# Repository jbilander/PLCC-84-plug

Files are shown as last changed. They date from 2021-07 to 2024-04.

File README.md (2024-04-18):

# PLCC-84-plug
A PLCC-84 plug adapter created out of PCBs

***
Please note, The first revision Rev1A of this plug isn't optimal for SMD-sockets, it is a little too small to give a solid connection on all pins. It fits well and gives good connection in the seemingly tighter PLCC-84-TH-sockets though. A new revision 1C is in the works aiming for that 30.1-30.2 mm sweetspot.

_UPDATE: The Rev.1C is finished and gerbers available for download under Releases as well:_

***

REV 1C:<br /><br />
<a href="images/PLCC_84_Plug_pcbs_rev1c.jpg">
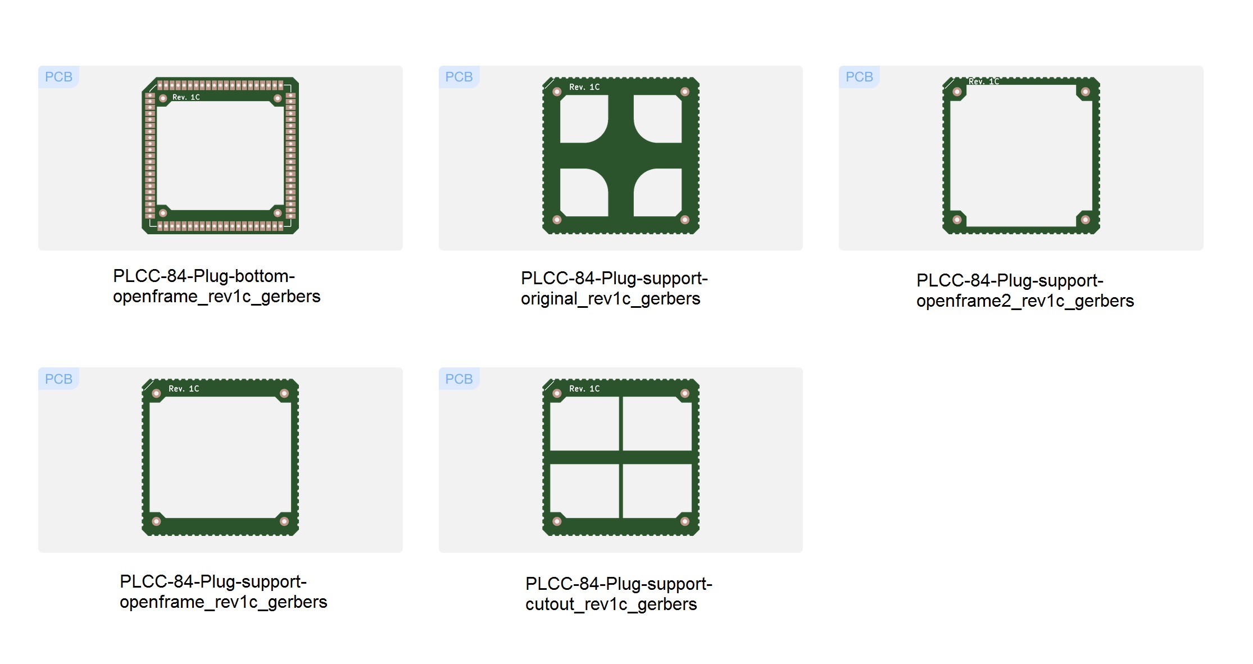
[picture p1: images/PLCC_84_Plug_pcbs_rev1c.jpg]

</a>

***

REV 1B:

<br />
<a href="images/PLCC_84_Plug_build_pic13.jpg">
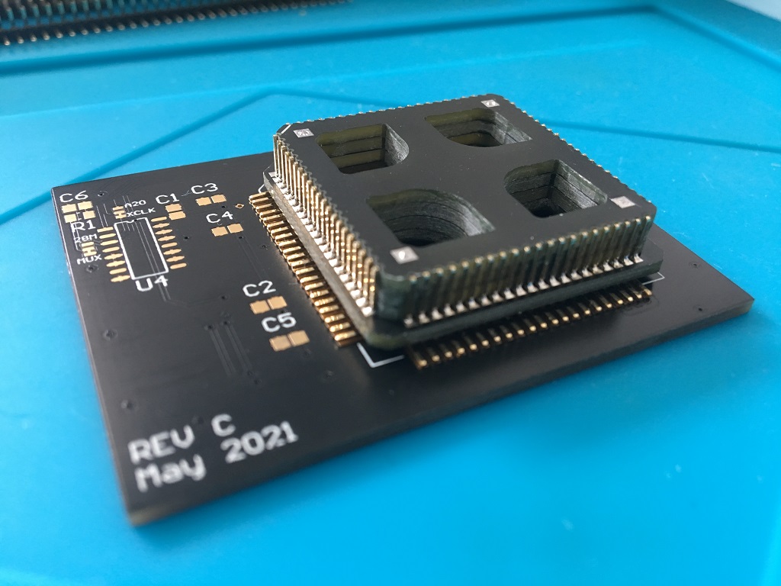
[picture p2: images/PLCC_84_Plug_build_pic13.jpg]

</a>
<br />

Suitable pin headers to use with this plug:<br />
1.27 mm 50 P 1 x 50 Pin Header Single row Right Angle Male<br />
https://www.aliexpress.com/item/32767692043.html
<br /><br />
If you use the pins from the link (0.4mm square) you will get to ~30.2 mm, with the MPE 332-1-040 pins you will end up at ~30.4mm which is perhaps a bit too much for a TH-socket.
<br /><br />
<a href="images/PLCC_84_Plug_build_pic16.jpg">
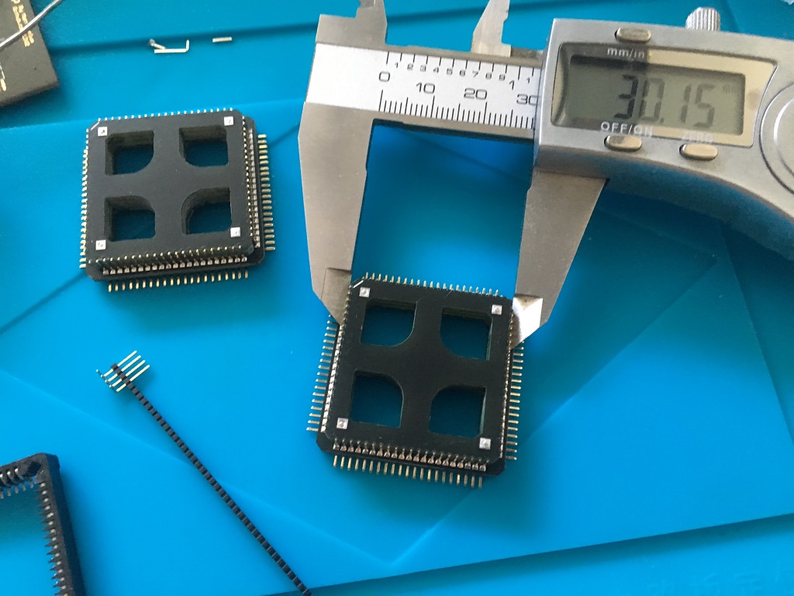
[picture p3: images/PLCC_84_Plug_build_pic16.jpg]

</a>
<a href="images/PLCC_84_Plug_build_pic15.jpg">
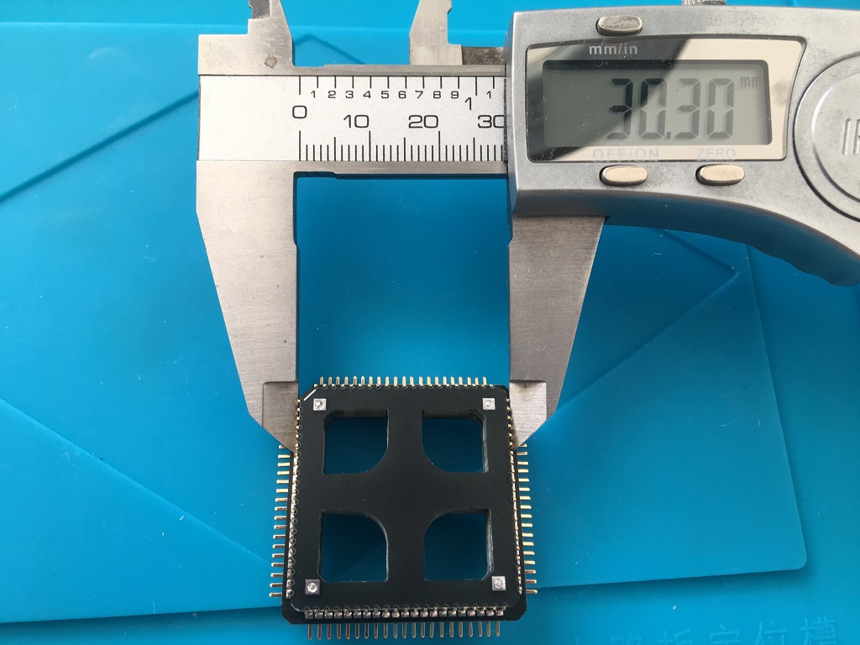
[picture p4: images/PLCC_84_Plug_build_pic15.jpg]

</a>
<a href="images/PLCC_84_Plug_build_pic14.jpg">
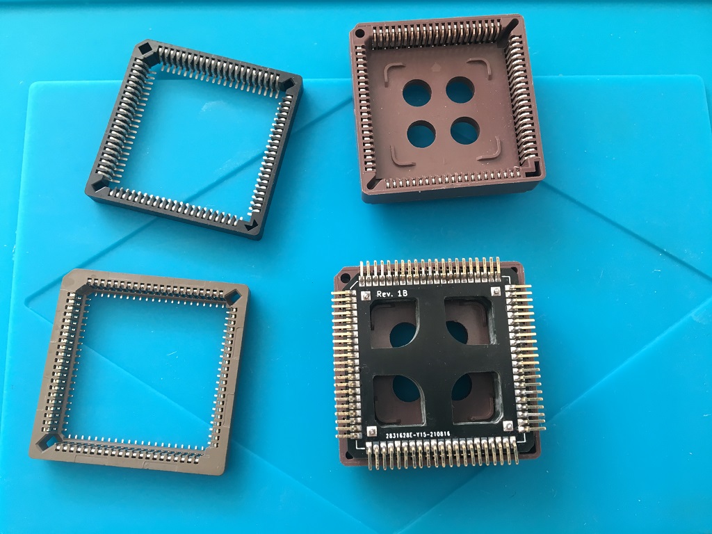
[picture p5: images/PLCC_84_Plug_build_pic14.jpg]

</a>

***

With this kind of footprint on the PCB it will take both variants of the plug. Both one with the angled SMT headers like above and one with straight TH-pins like on pics below. As you can see there's no need for the base PCB in the latter case since that footprint is now directly on the main PCB.

***

<a href="images/PLCC_84_Plug_build_pic18.jpg">
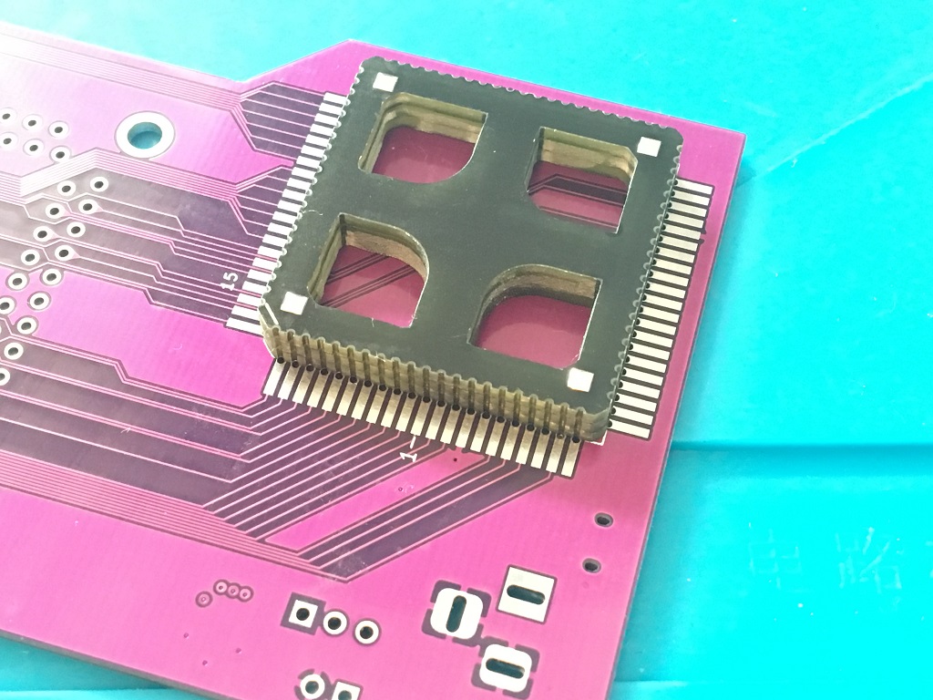
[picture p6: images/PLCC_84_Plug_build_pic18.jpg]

</a>
<a href="images/PLCC_84_Plug_build_pic19.jpg">
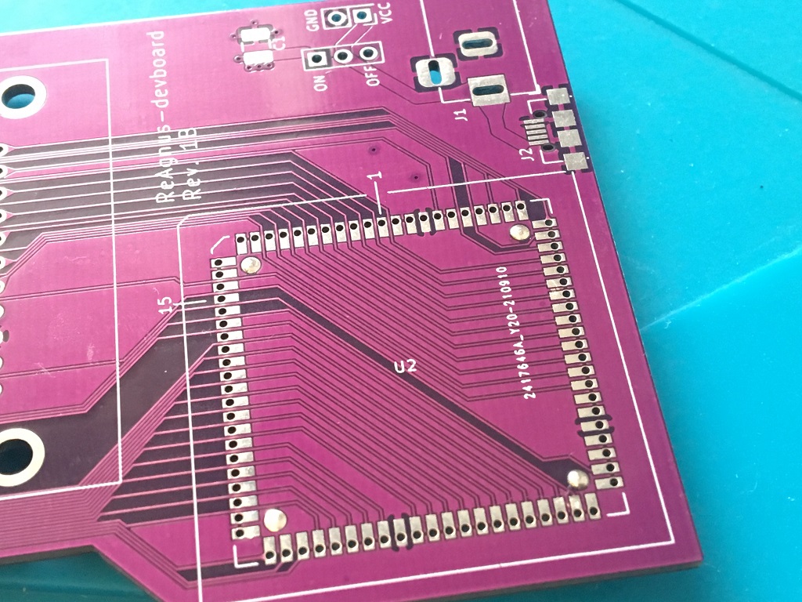
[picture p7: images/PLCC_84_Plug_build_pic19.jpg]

</a>
<a href="images/PLCC_84_Plug_build_pic20.jpg">
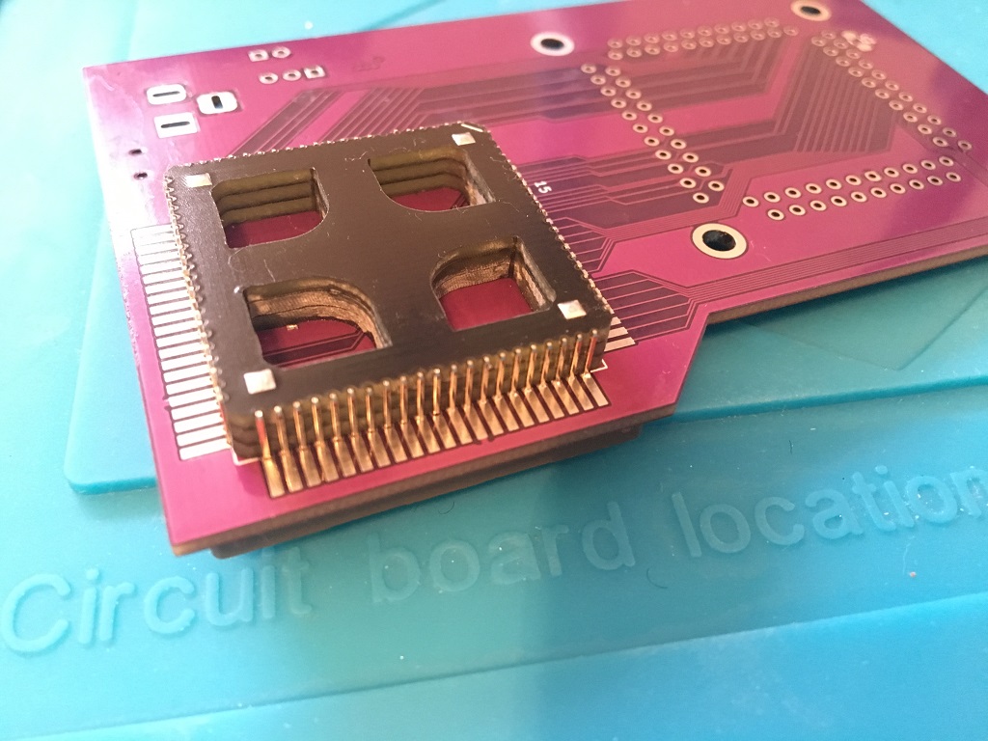
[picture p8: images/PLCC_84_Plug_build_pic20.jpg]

</a>

***

REV 1A:

<br />
<a href="images/PLCC_84_HomebrewPlug_rev1a_vs_Winslow_plug.jpg">
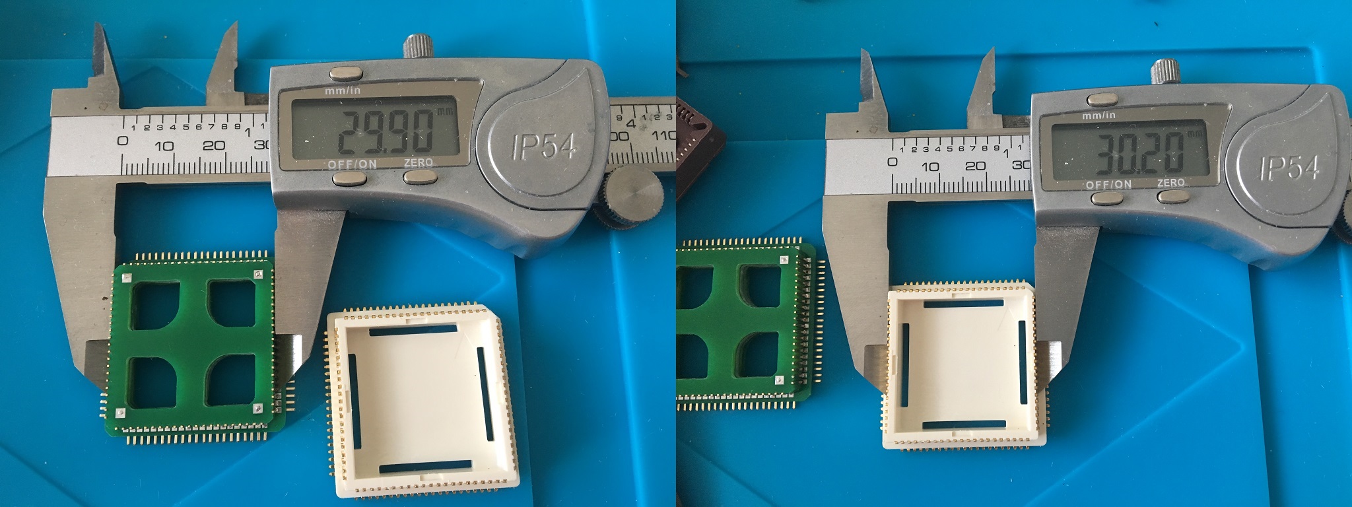
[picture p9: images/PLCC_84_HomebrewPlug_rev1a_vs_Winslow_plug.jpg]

</a>
<br />

Suitable pin headers to use building this plug:<br />
_MPE 332-1-040 Pin headers 2.00 mm, 1X40, angled_ <br />
https://www.reichelt.com/se/en/pin-headers-2-00-mm-1x40-angled-mpe-332-1-040-p119983.html

***

Building: <br />

First use a TH-socket as a Jig and put three support PCBs in the socket, pay attention to orientation (the silk screen marking in the corner). Now put two straight header pins (taken from a 2.0mm pin pitch header) in each corner to center align the PCBs. Now put the bottom PCB in place and put fatter pins (from a 2.54mm pin pitch header) in each of the TH-pad corners and solder to lock everything in position. Cut the four pins with a wire cutter<br />

***

<a href="images/PLCC_84_Plug_build_pic1.jpg">
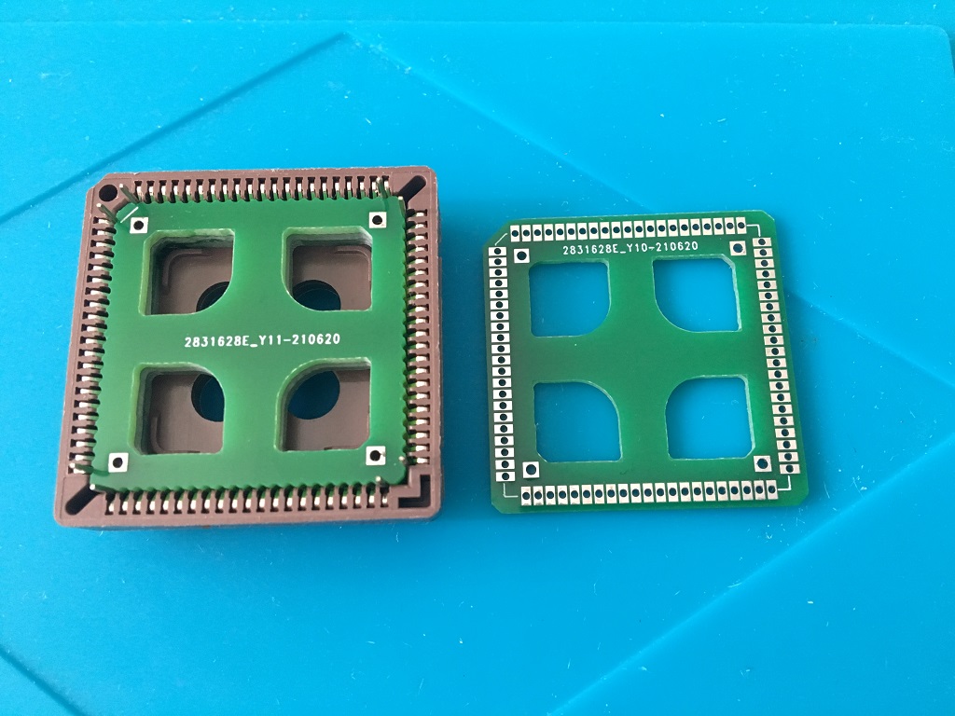
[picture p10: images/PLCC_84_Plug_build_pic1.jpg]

</a>
<a href="images/PLCC_84_Plug_build_pic2.jpg">
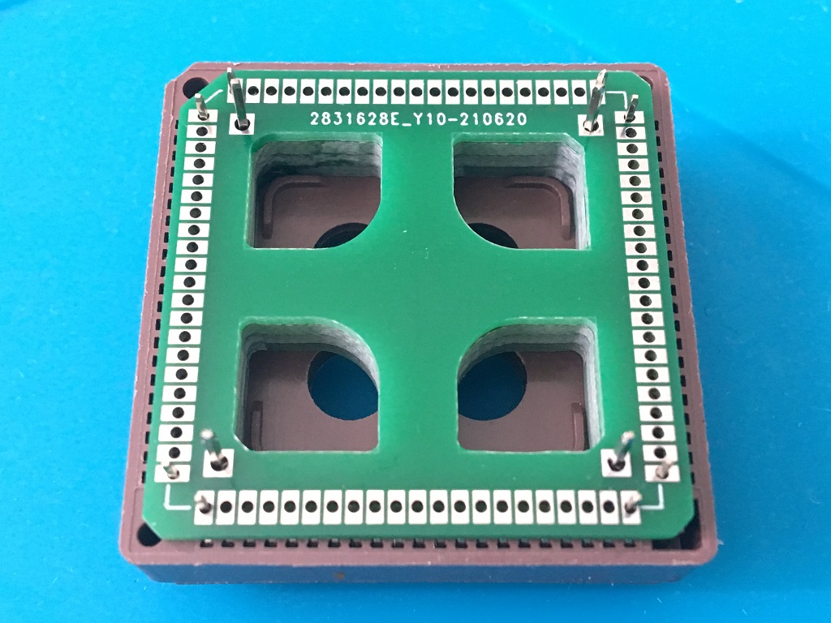
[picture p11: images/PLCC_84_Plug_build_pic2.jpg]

</a>
<br />
<a href="images/PLCC_84_Plug_build_pic3.jpg">
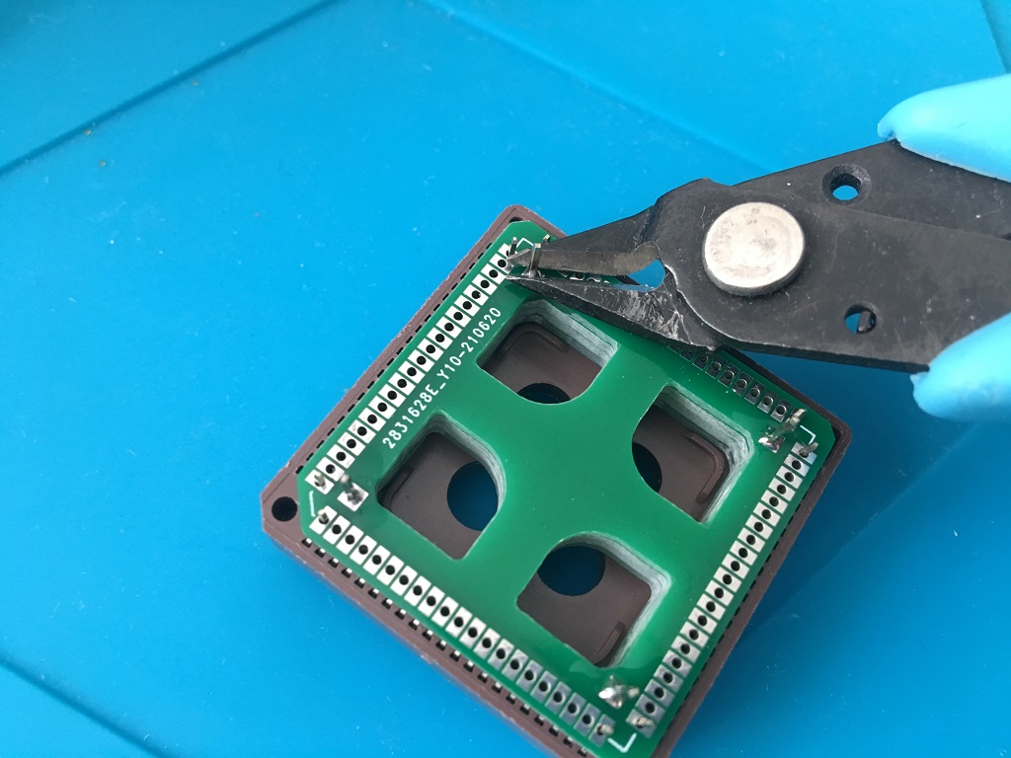
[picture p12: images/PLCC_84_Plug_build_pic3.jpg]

</a>
<a href="images/PLCC_84_Plug_build_pic4.jpg">
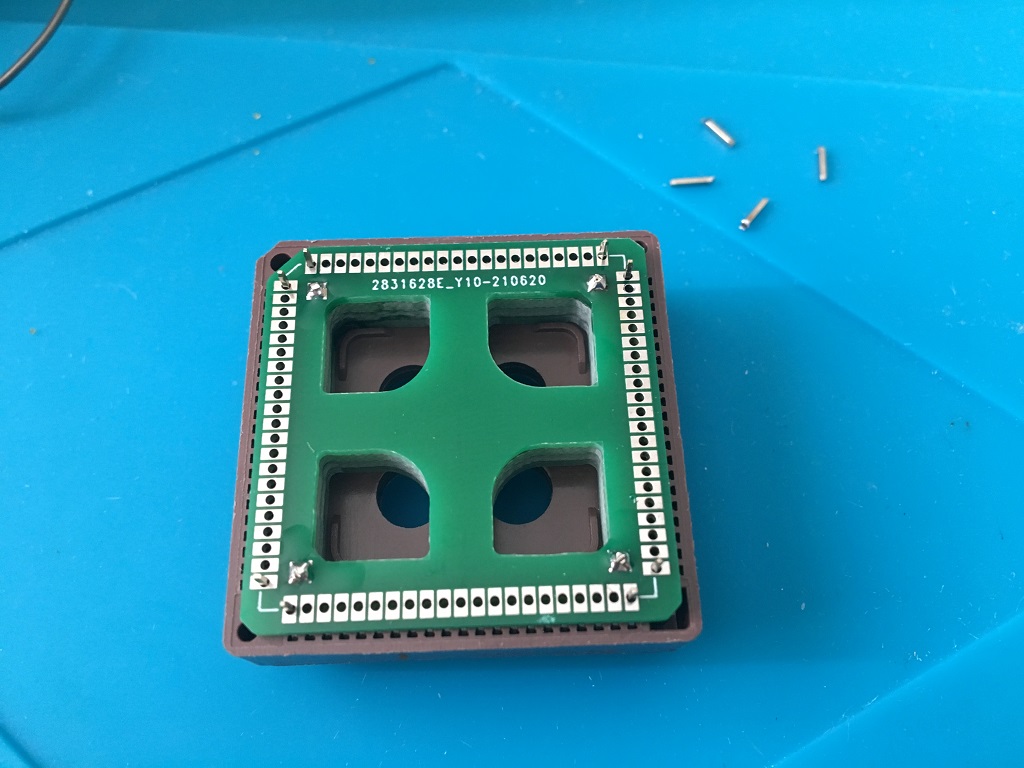
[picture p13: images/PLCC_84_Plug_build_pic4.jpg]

</a>

***

To remove the pins from the plastic strip give them a push with a heated solder iron and they will come out easy. Now remove one of the straight pins and start populate with angled pins using the straight pin as a spacer, and start solder them down. Rinse and repeat until done.

***

<a href="images/PLCC_84_Plug_build_pic5.jpg">
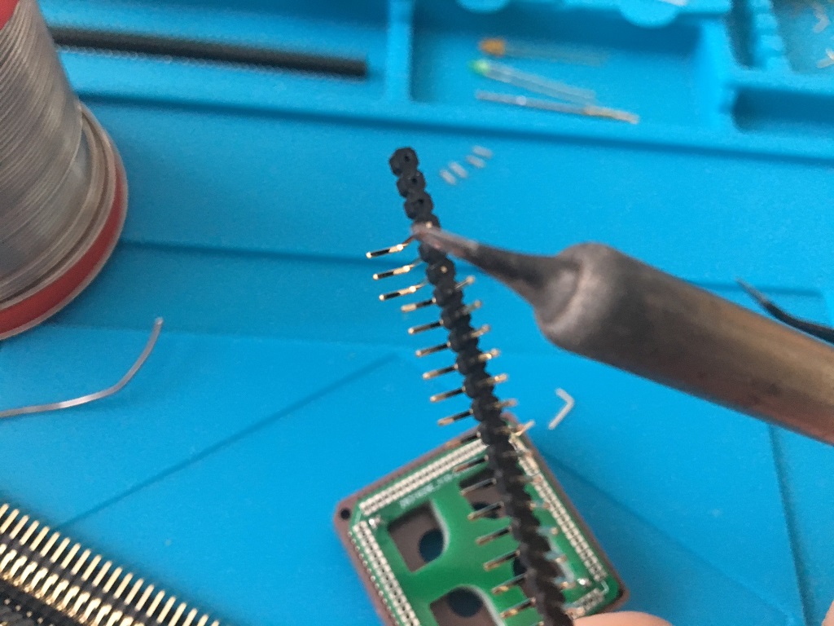
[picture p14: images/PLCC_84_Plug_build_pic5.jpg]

</a>
<a href="images/PLCC_84_Plug_build_pic6.jpg">
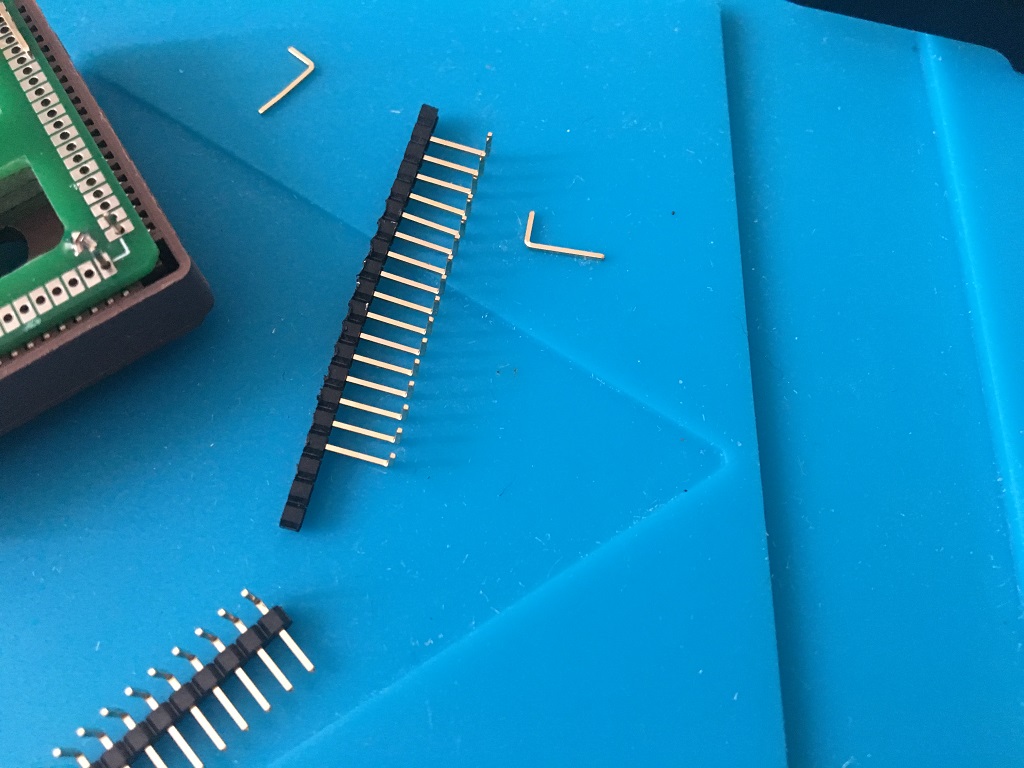
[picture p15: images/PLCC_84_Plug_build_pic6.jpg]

</a>
<br />
<a href="images/PLCC_84_Plug_build_pic7.jpg">
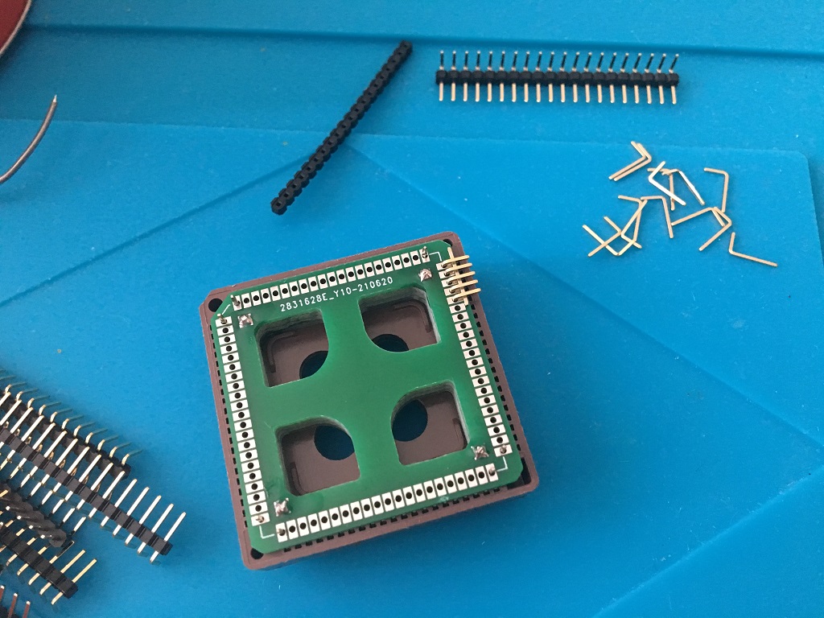
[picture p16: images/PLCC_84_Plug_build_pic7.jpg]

</a>
<a href="images/PLCC_84_Plug_build_pic8.jpg">
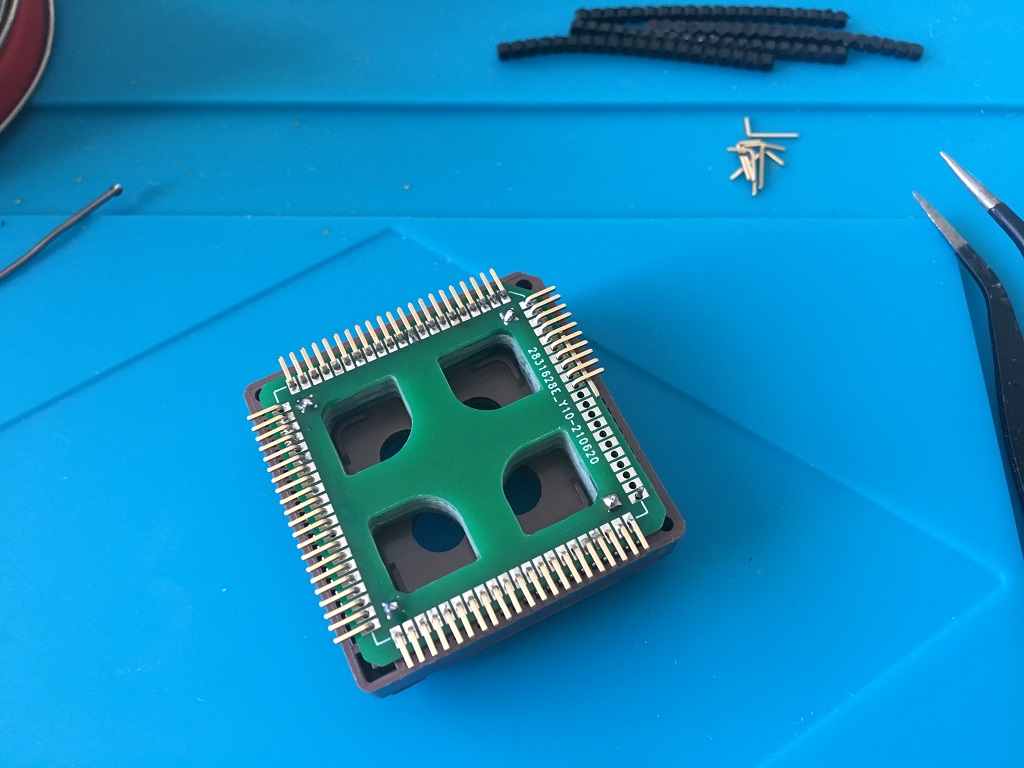
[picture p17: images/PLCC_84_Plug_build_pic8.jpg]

</a>

***

I discovered a good technique to use when soldering the 0.4mm square pins (1.27 mm pin pitch) is to reuse the plastic like in picture below while soldering to get everything to align and look very nice.

***

<a href="images/PLCC_84_Plug_build_pic17.jpg">
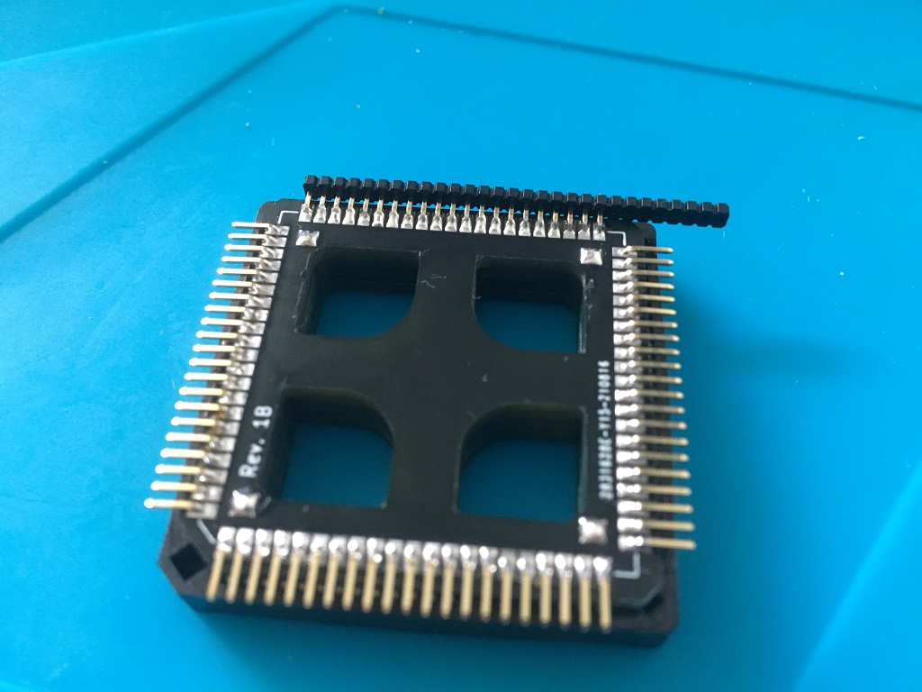
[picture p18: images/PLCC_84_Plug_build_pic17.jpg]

</a>

***

When done, use a flat screwdriver and work/lever on the corners elevating the plug a little at a time until it comes out of the socket.

***

<a href="images/PLCC_84_Plug_build_pic9.jpg">
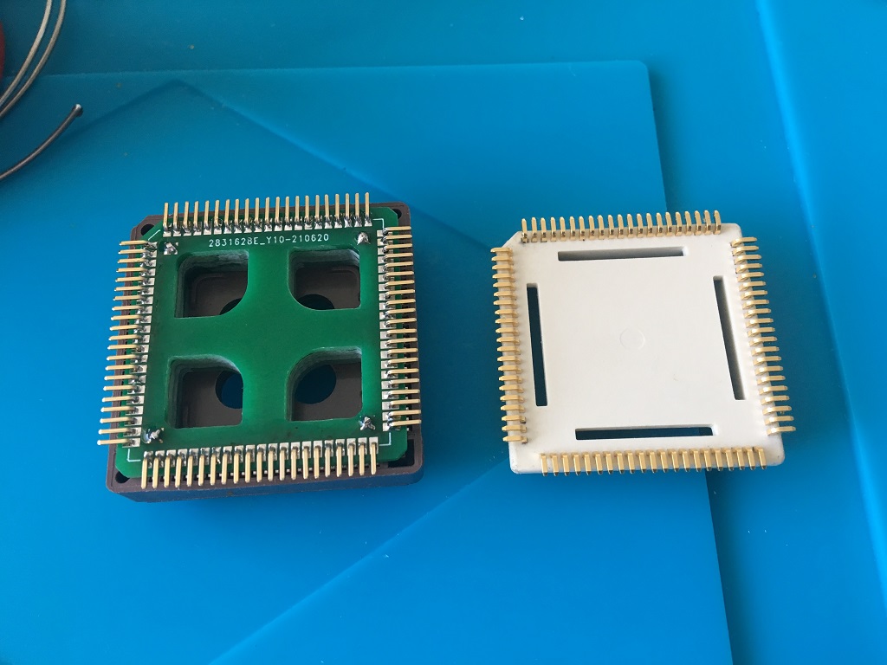
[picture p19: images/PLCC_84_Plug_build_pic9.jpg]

</a>
<a href="images/PLCC_84_Plug_build_pic10.jpg">
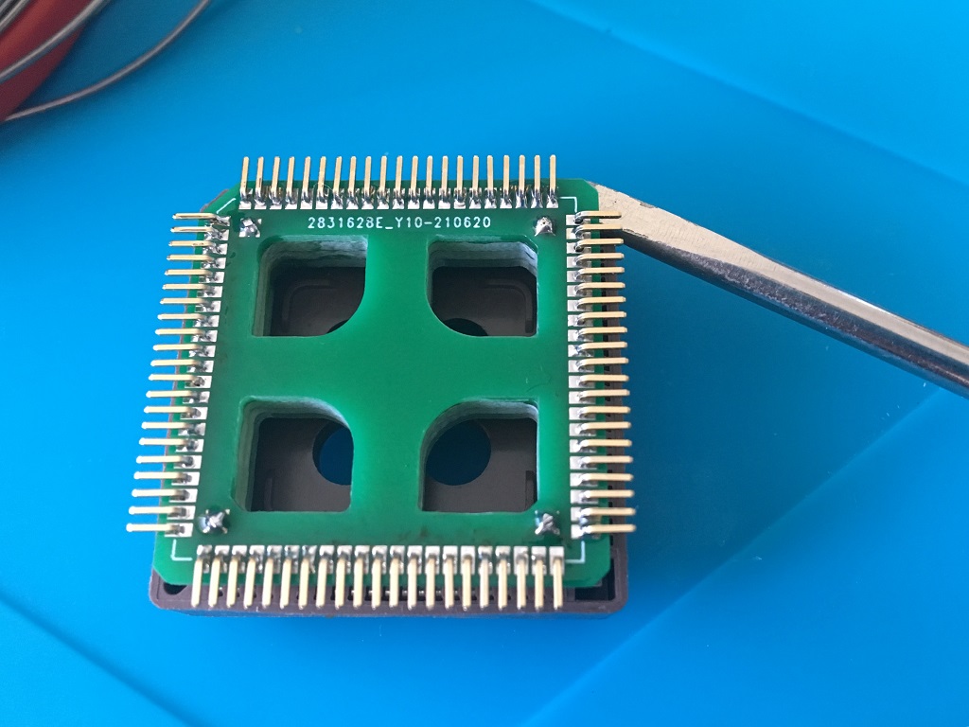
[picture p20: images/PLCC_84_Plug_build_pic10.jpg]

</a>
<br />
<a href="images/PLCC_84_Plug_build_pic11.jpg">
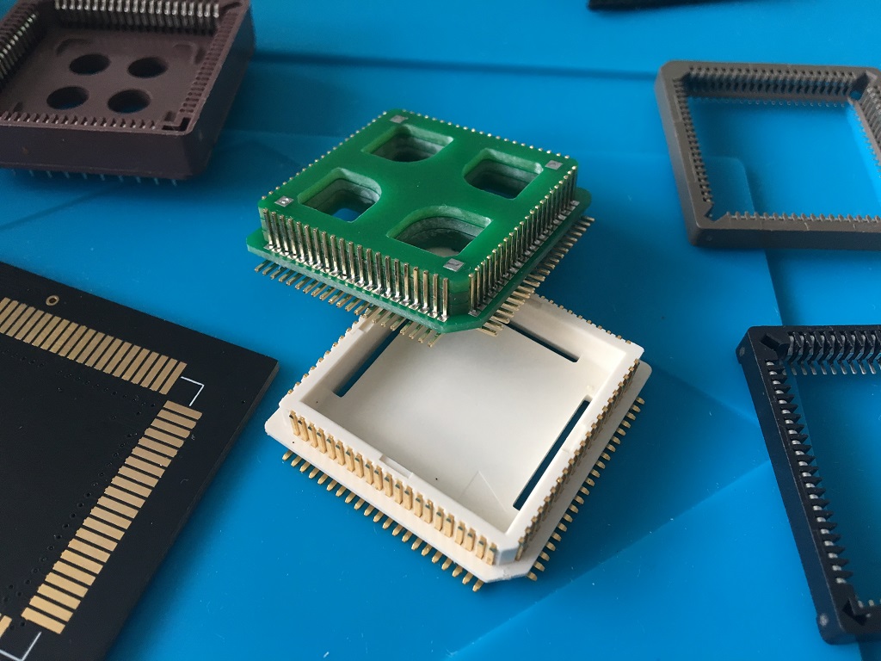
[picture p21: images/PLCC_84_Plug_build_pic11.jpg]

</a>
<a href="images/PLCC_84_Plug_build_pic12.jpg">
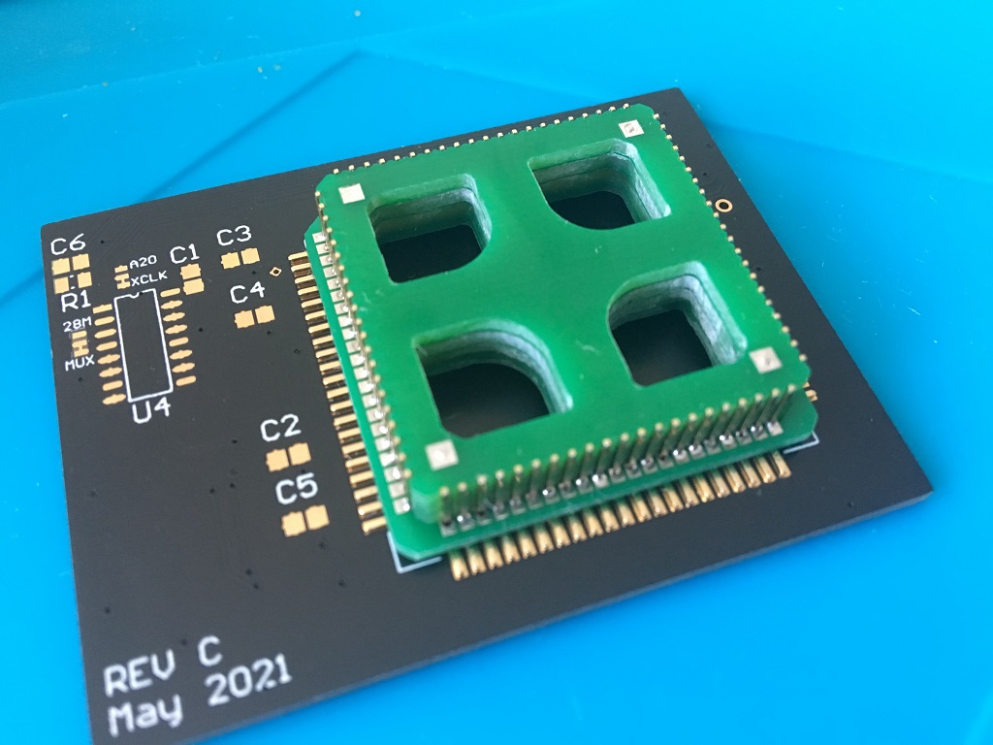
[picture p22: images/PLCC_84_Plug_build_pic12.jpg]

</a>

***

All done! Happy Hackin'

***

REV 1A:<br /> built with pins used from a SMT header like this: <br />
https://www.aliexpress.com/item/1005002683388545.html <br />
They are not optimal in terms of pin-terminal length. <br />

<a href="images/PLCC_84_Plug_pic1.jpg">
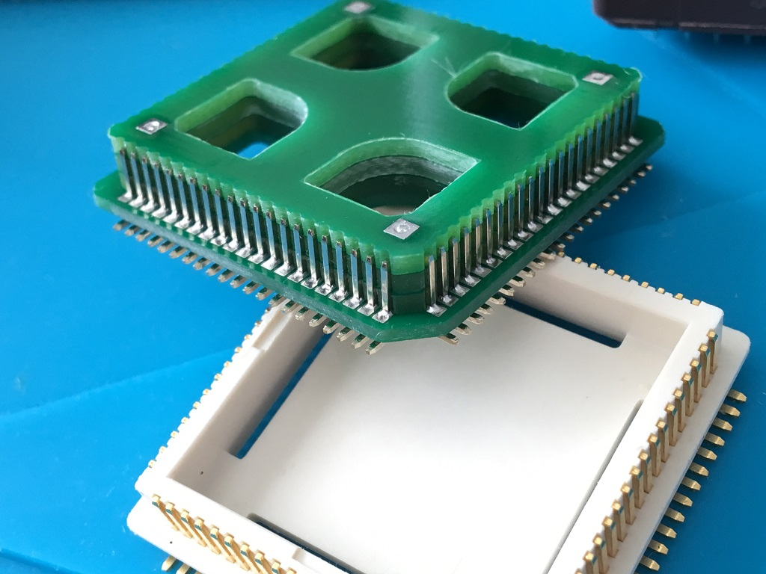
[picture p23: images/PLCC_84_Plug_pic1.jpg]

</a>
<a href="images/PLCC_84_Plug_pic2.jpg">
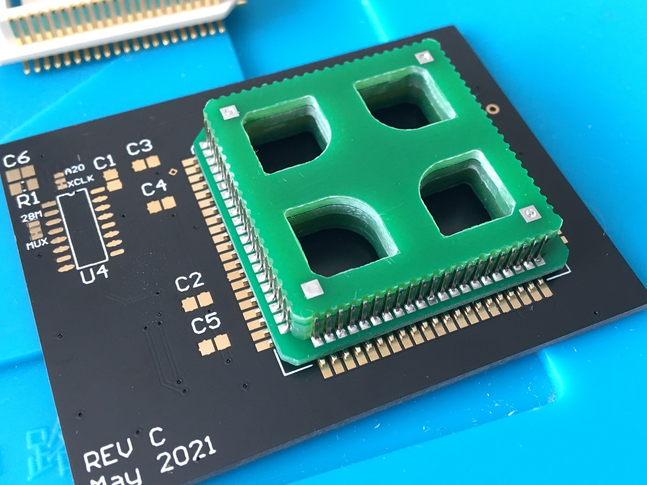
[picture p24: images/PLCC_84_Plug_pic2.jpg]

</a>

<a href="images/PLCC_84_Plug_build.jpg">
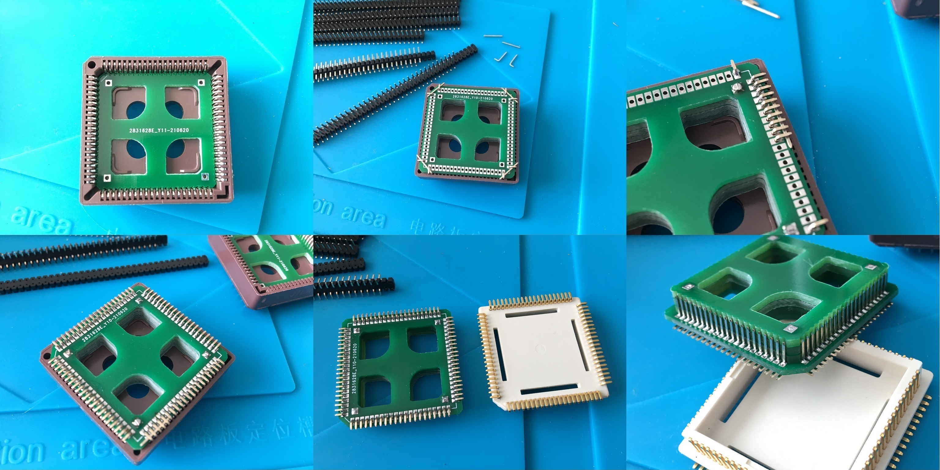
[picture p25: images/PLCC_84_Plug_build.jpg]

</a>

***

[][cc-by-sa]

This work is licensed under a
[Creative Commons Attribution-ShareAlike 4.0 International License][cc-by-sa].

[][cc-by-sa]

[cc-by-sa]: http://creativecommons.org/licenses/by-sa/4.0/
[cc-by-sa-image]: https://licensebuttons.net/l/by-sa/4.0/88x31.png
[cc-by-sa-shield]: https://img.shields.io/badge/License-CC%20BY--SA%204.0-lightgrey.svg

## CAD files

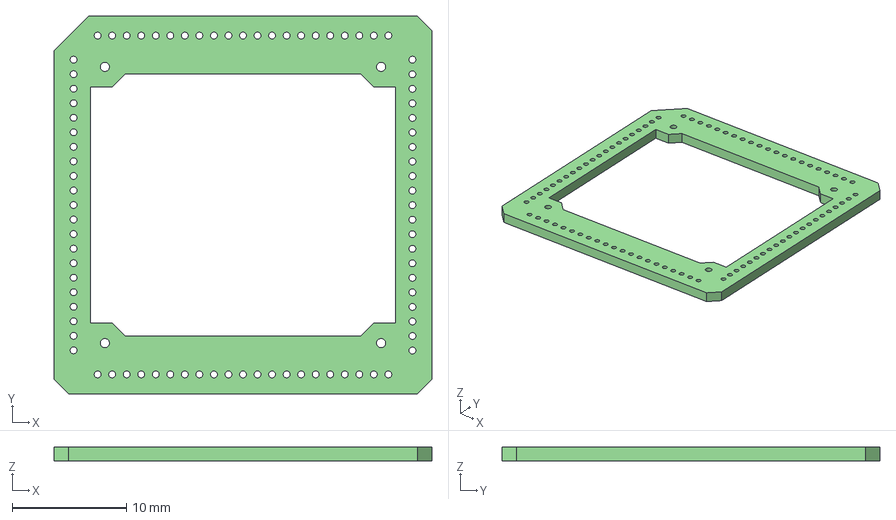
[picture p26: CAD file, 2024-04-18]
3D-models/PLCC-84-Plug-bottom-openframe_rev1c.step
33.0 x 33.0 x 1.20 mm

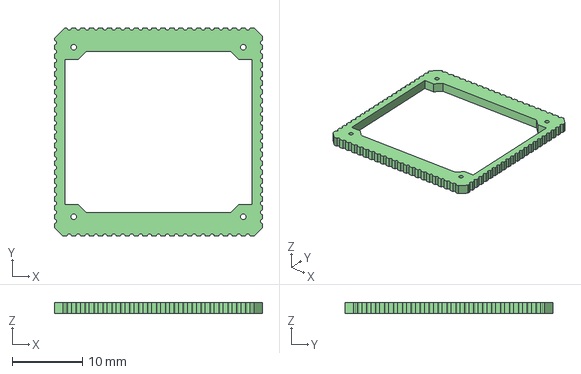
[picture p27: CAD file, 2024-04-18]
3D-models/PLCC-84-Plug-support-openframe_rev1c.step
29.6 x 29.6 x 1.60 mm

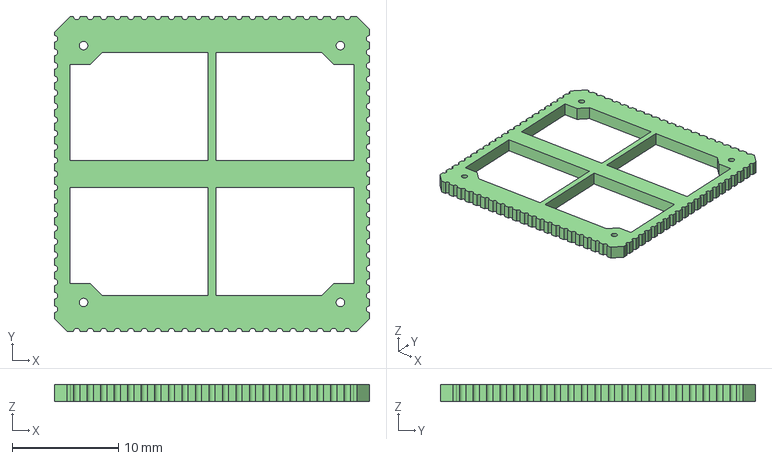
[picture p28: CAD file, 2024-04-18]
3D-models/PLCC-84-Plug-support-cutout_rev1c.step
29.6 x 29.6 x 1.60 mm

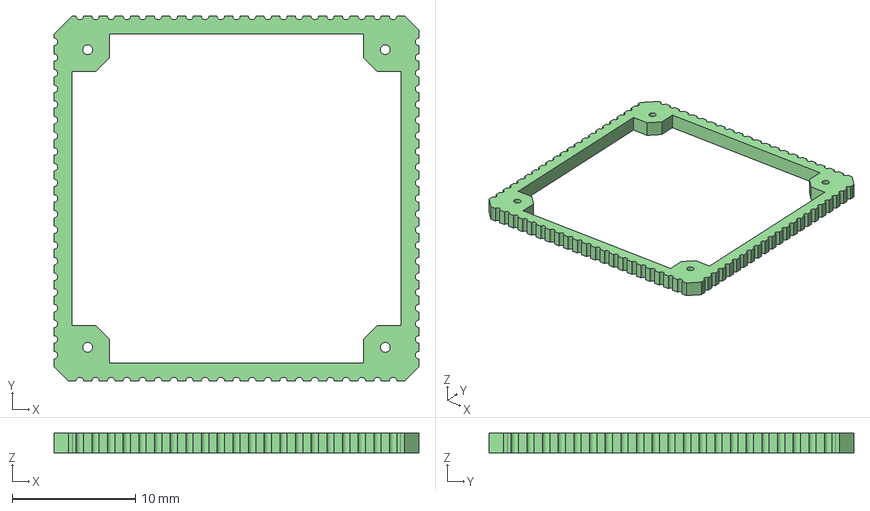
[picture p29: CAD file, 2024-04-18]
3D-models/PLCC-84-Plug-support-openframe2_rev1c.step
29.6 x 29.6 x 1.60 mm

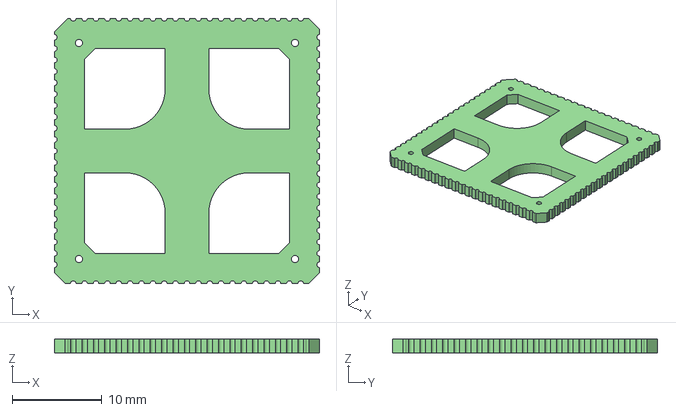
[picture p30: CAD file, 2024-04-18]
3D-models/PLCC-84-Plug-support-original_rev1c.step
29.6 x 29.6 x 1.60 mm

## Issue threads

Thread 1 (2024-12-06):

Inquiry about a custom Amiga project

2mg, 2024-12-06:
Hello,

I saw your Amiga oriented GitHub repositories, and saw your [PLCC-84-plug](https://github.com/jbilander/PLCC-84-plug).

I'm asking if you'd be willing to consider making a dual Agnus 2xPLCC socket board with a switcher.

As I like to do as little fiddling as possible with old hardware, having an Agnus switcher (between OCS and ECS, specifically 1MB only) would mean a tremendous lot for me, as I'd plug that in once, forget about it and reduce any further strenuous activity on that Agnus socket and Agnus itself.

There is even a PLCC84 plug from 2 different sources for fitting this custom board into the Agnus socket, and since I want only the 1MB 8372(A) ECS Agnus (there are 2 specific 8375 1MB that are pin compatible too) there is no need for any converters.

If you're interested, I can make a little donation, or buy it straight from you preassembled, the BOM will possibly be really small AFAIK, I can source my own Agnuses.

You could further experiment with this approach to switch between OCS and ECS 2MB versions, but I just need the OCS and ECS 1MB approach.

Please let me know if you plan on doing this!

jbilander, 2024-12-06:
Hi, I'm not quite sure I follow what you are after. You want a board with one plug (that installs to the motherboard) and two PLCC-84 sockets on top, one socket for OCS Agnus and one for ECS Agnus? and then be able to switch between them (be it offline).

OCS Agnus (8371 or earlier) can only address up to 512 kB of Chip RAM and the ECS Agnus supersedes it so I must be missing something why you simply just don't replace the OCS version? If your ECS Agnus has the other pinout there are already adapter boards out there for this purpose where you can retrofit for example a ECS Agnus 390544-01 that normally sits in an A500+/A600 but can be fitted into a machine that take the other pinout (A500, A2000, A3000).

This page is a good source just to clarify OCS vs. ECS when we talk about Agnus, the _Chips by capability_ section...
https://en.wikipedia.org/wiki/MOS_Technology_Agnus

2mg, 2024-12-07:
Hi,

My request might sound weird, but the idea is to keep the original hardware
my Amiga came from (OCS Agnus) for max compatibility and a bit of simply
keeping original hardware inside with a switch to ECS1MB Agnus, without
fiddling with 40 year old plastics once I plop the switchboard in.

I know I can just plop in ECS 1MB Agnus, or get a board for 2MB Agnus, but
as I said, I'm looking for a mix of original hardware with an on demand
upgrade.

Did I make more sense?

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

jbilander, 2024-12-08:
Hi, ok I see.

Yeah that is a bit of an odd request. The ECS Agnus can do all that your OCS Agnus can do plus more so you won't lose any compatibility, but rather you increase it since ECS Agnus can also switch between PAL and NTSC mode. There's no reason for having the OCS Agnus around once you have the ECS Agnus installed. Just tape it somewhere inside the case if you don't wanna lose it and keep it with the machine it came.

A very common modification that people do with for example a Rev 5 A500 is to replace the OCS 8370/8371 with a ECS 8372A in order to be able to have a system with 1 MB of Chip RAM. Pin 41 on 8372A controls startup mode PAL or NTSC. What people often do in order to have the system startup in PAL mode is to put a small piece of kapton tape on the chip pin 41 to isolate the pin from touching the corresponding socket pin (which is normally grounded on the motherboard), if that pin is grounded it means startup in NTSC-mode.

2mg, 2024-12-08:
Pretty much boils to what you said - just tape it somewhere.

Which give me an idea - why not still have it plugged in, somehow.

There are so many physical switchers and boards, so why not Agnus, seemed
like just a few sockets and a bunch of traces (dunno about the switcher
tho) kind of project.

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

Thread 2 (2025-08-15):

Question Pin-headers rev.1D

amiconretrotv, 2025-08-15:
Hello, I ordered the revision 1D PLCC plug and I have a question about the pin headers. You say that 2.0 mm and 0.5 mm ones fit well into the PLCC84 socket, I bought some 2.00mm and 0.5mm ones, and when I tried to insert them into the 3 PCBs in the pin guide, the last pin was about 1mm too short and didn't reach the edge. So I'm not sure if the pin headers I received are defective. If you have a link where I can purchase the correct pins, I would appreciate it. Best regards and great work.

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

jbilander, 2025-08-15:
I had a quick look at aliexpress, perhaps you could take pins from a double row pin header like this?

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

The shorter pin there seems to be:
4 + 5,4 - 2 =  7,4 mm long

https://www.aliexpress.com/item/1005007309474559.html

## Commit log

2021-07-04 added KiCad files
    [PLCC-84-Plug-bottom.kicad_pcb, PLCC-84-Plug-bottom.sch, PLCC-84-Plug-support.kicad_pcb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]
2021-07-04 added Rev1A gerbers
2021-07-07 moved gerbers to project root folder
2021-07-30 removed rev1a gerber zip files, will be put in release 1A instead
2021-08-01 made a new revision 1B with modified size
    [PLCC-84-Plug-bottom.kicad_pcb, PLCC-84-Plug-support.kicad_pcb]
2023-07-23 Re-design of dimensions and cut-outs to fit level-shifters on underside, Rev. 1C
    [PLCC-84-Plug-support.kicad_pcb]
2023-07-23 small fix SolderMaskClearance setting
    [PLCC-84-Plug-bottom.kicad_pcb, PLCC-84-Plug-support.kicad_pcb]
2023-07-23 openframe version of Rev. 1C
    [PLCC-84-Plug-support.kicad_pcb]
2023-07-23 Updated footprint for Rev. 1C dimensions
2023-07-23 Updated dimensions and openframe to support level shifters on underside, Rev 1C
    [PLCC-84-Plug-bottom.kicad_pcb]
2023-07-27 Original design Rev.1C
    [PLCC-84-Plug-support.kicad_pcb]
2023-07-27 small fix of cut-out Rev.1C bottom pcb
    [PLCC-84-Plug-bottom.kicad_pcb]
2023-07-27 Openframe version support pcb Rev.1C
    [PLCC-84-Plug-support.kicad_pcb]
2023-07-27 cutout-version support pcb Rev.1C
    [PLCC-84-Plug-support.kicad_pcb]
2023-07-27 Added 3D-models
    [PLCC-84-Plug-bottom-openframe_rev1c.step, PLCC-84-Plug-support-cutout_rev1c.step, PLCC-84-Plug-support-openframe_rev1c.step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]
2023-07-30 openframe2 design
    [PLCC-84-Plug-support.kicad_pcb]
2023-07-30 Added 3D-model
    [PLCC-84-Plug-support-openframe2_rev1c.step]
2024-04-18 updated image with latest rev1c gerber pics

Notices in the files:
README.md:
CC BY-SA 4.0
